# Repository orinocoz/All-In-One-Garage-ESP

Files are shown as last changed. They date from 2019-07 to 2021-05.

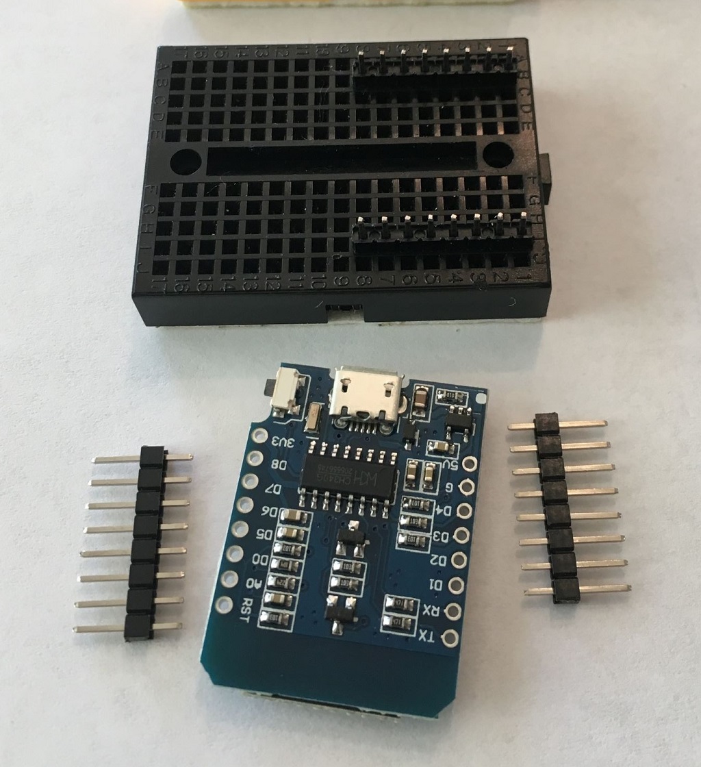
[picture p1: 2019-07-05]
Docs/D1 Mini Some Soldering Required.jpg

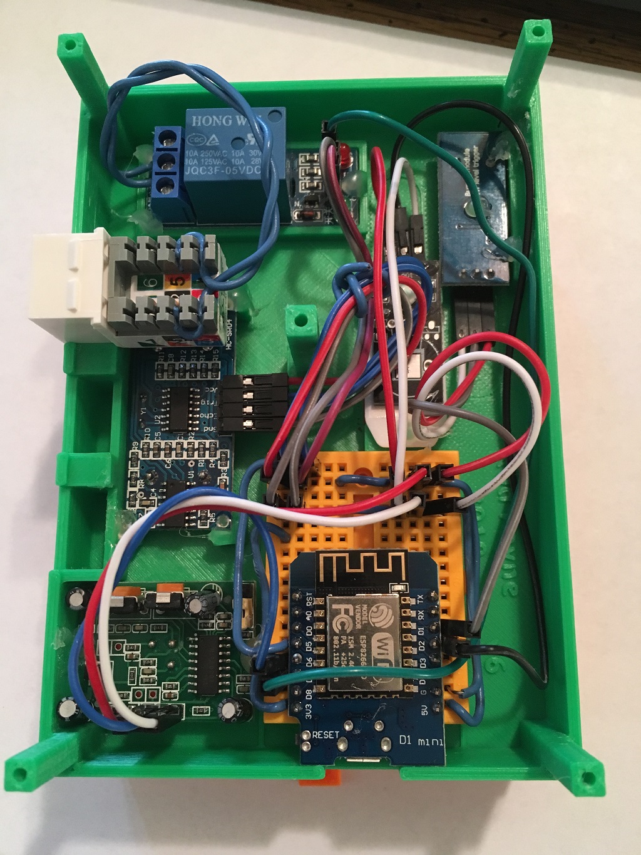
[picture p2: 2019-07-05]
Docs/Controller Wiring.JPG

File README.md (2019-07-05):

# All-In-One-Garage-ESP
All-In-One Garage Controller on ESP8266 (WeMos D1 Mini)

Communicates over WiFi to MQTT broker, for Home Assistant or other system.
As built, for two car bays with one door.

## Parts List

- [WeMos D1 Mini Module](<https://www.aliexpress.com/item/D1-mini-Mini-NodeMcu-4M-bytes-Lua-WIFI-Internet-of-Things-development-board-based-ESP8266-by/32644199530.html>)
- [Power Supply 5V Micro USB](<https://www.amazon.com/Raspberry-Power-Supply-Adapter-Charger/dp/B0719SX3GC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>)
- [5V Relay Module (2 needed, or a 2 channel relay, if for two doors)](<https://www.aliexpress.com/item/one-1-channel-relay-module-with-optocoupler-isolation-fully-compatible-with-3-3V-and-5V-Signal/32869288345.html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>) - Relay needs to trip with 3.3V and **_low current_**.
- [Magnetic Contact Switch (2 needed if for two doors)](<https://www.aliexpress.com/item/NO-NC-Wired-Door-Magnetic-Contact-Switch-alarm-Reed-switches-door-sensor-for-Home-Alarm-System/32832532279.html>)
- Jumper wires, etc.

Following are optional:
- [HC-SR04 Distance Sensor (1/5, 2 needed if for two car bays)](<https://www.amazon.com/gp/product/B01GVDV6DY/ref=oh_aui_detailpage_o01_s02?ie=UTF8&psc=1>)
- [Passive Buzzer Alarm Module](<https://www.dx.com/p/passive-low-level-buzzer-alarm-module-for-arduino-dc-3-5v-5v-2017987#.XAF3AeJlCUk>)
- [RJ11 Keystone Jack (2 needed if for one car bay, 4 if for two car bays, 6 if for two doors/two bays)](<https://www.homedepot.com/p/Commercial-Electric-Voice-Grade-Jack-White-5023-WH/206427969>)
- [DHT22 AM2302 Digital Temperature and Humidity Sensor](<https://www.amazon.com/TOOGOO-Digital-Temperature-Humidity-Raspberry/dp/B0757F4KK3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>)
- [HC-SR501 PIR (motion) sensor](<https://www.adafruit.com/product/189>)
- [Mini Breadboard Kit (1/6)](<https://www.amazon.com/gp/product/B01EV6SBXQ/ref=oh_aui_detailpage_o05_s00?ie=UTF8&psc=1>)
- Main Project Case ([Garage Parts - Main - Bottom.stl](<Garage Parts - Main - Bottom.stl>) and [Garage Parts - Main - Top.stl](<Garage Parts - Main - Top.stl>))
- Remote Project Case if for two car bays ([Garage Parts - Remote - Bottom.stl](<Garage Parts - Remote - Bottom.stl>) and [Garage Parts - Remote - Top.stl](<Garage Parts - Remote - Top.stl>))

Approximate total cost $50.00

## Wiring for one door and two cars

- D1 - Speaker I/O
- D2 - DHT22 Out
- D3 - Don't use, controls run/flash mode
- D4 - Controls LED, but could be used
- G - Left Echo Gnd - Right Echo Gnd (to jack) - DHT22 Gnd(-) - Motion Gnd - Left Relay Gnd - Speaker Gnd - Left Mag Switch N/C
- 5v - Left Echo Vcc - Right Echo Vcc (to jack) - DHT22 Vcc(+) - Motion +5v - Left Relay 5v - Speaker Vcc

- D0 - Right Echo Trig/Echo (to jack)
- D5 - Left Echo Trig/Echo
- D6 - Motion Out
- D7 - Left Relay
- D8 - Left Mag Switch Comm
- 3v - (Maybe Speaker Vcc)

Note: Building for two doors and two bays with all the options will require more ports than the WeMos D1 Mini Module normally supplies.  (The TX/RX ports could be used if you don't need the serial monitor for debugging, but this would require some reprogramming of the sketch.)

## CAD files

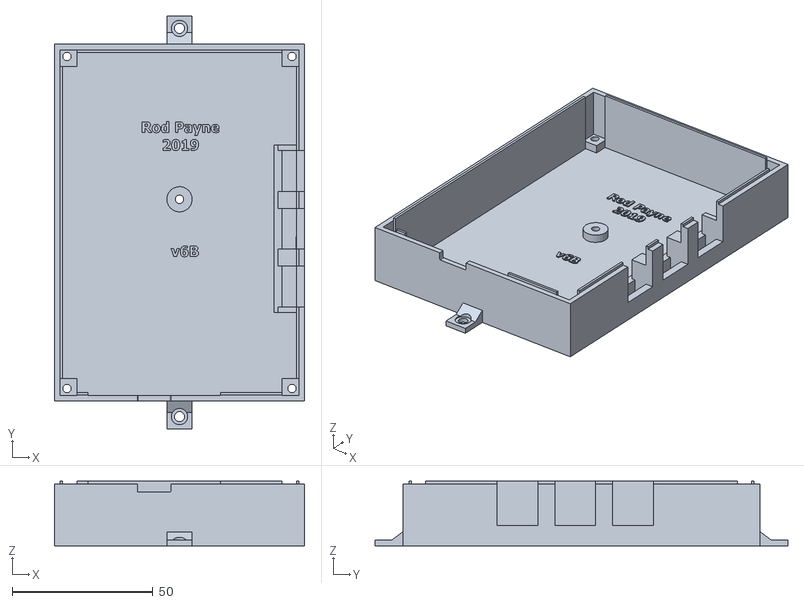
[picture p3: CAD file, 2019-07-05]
Garage Parts - Main - Bottom.stl
89.0 x 146.8 x 23.0

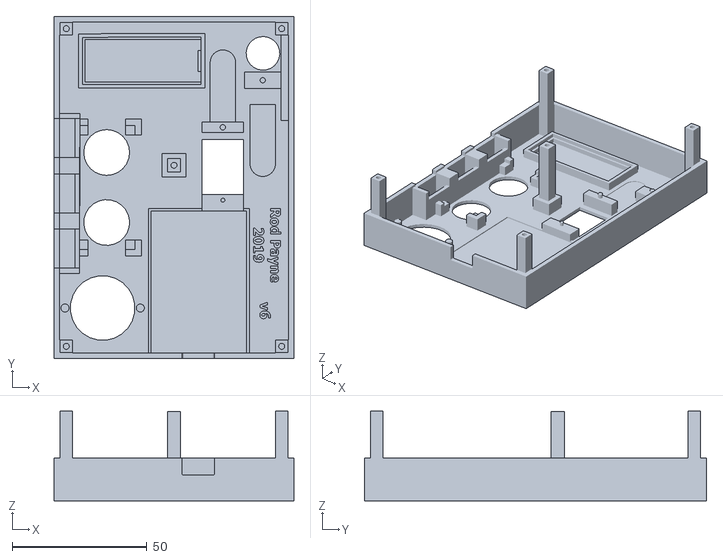
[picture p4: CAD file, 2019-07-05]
Garage Parts - Main - Top.stl
89.0 x 127.0 x 33.4

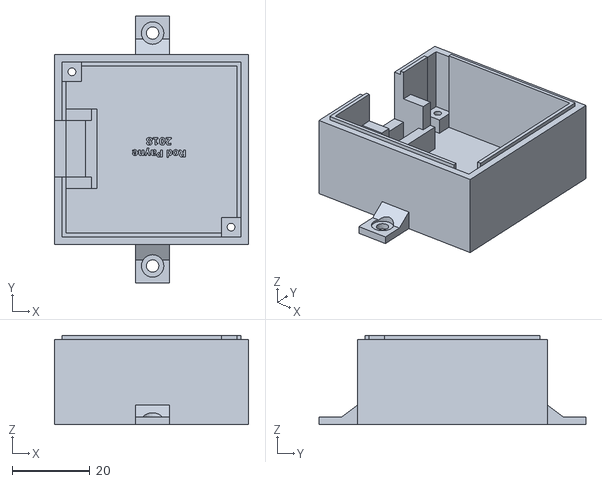
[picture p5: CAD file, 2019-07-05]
Garage Parts - Remote - Bottom.stl
50.0 x 68.8 x 23.0

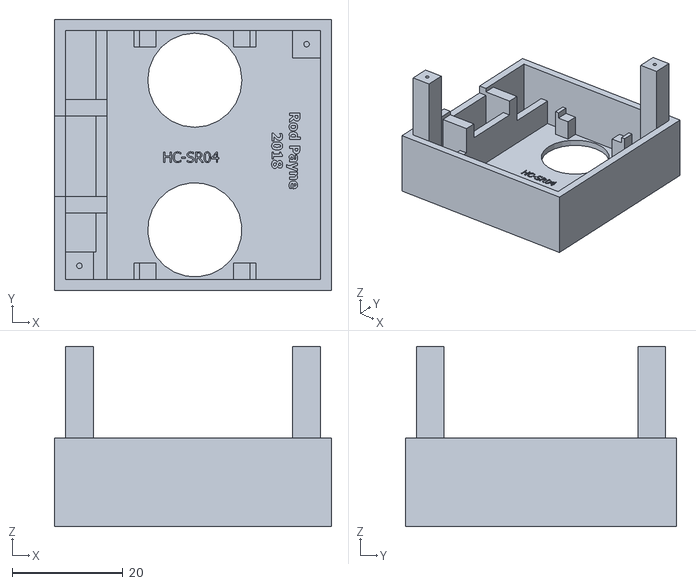
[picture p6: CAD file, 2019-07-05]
Garage Parts - Remote - Top.stl
50.0 x 49.0 x 32.5

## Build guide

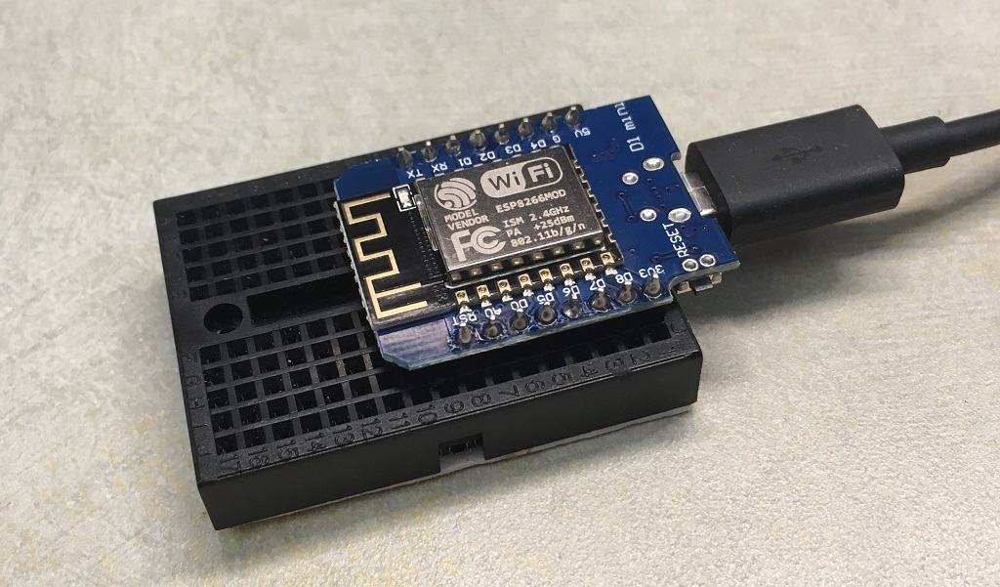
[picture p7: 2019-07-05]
Docs/D1 Mini Soldered Unit.JPG

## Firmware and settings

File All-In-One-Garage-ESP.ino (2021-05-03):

//*------------------------------------------------------------------------------------------------------------------------
//* All-In-One Garage Controller on ESP8266 (WeMos D1 Mini)
//*
//* See https://automatedhome.party/2017/01/06/wifi-garage-door-controller-using-a-wemos-d1-mini/
//* https://github.com/tzapu/WiFiManager/blob/master/examples/AutoConnectWithFSParameters/AutoConnectWithFSParameters.ino
//* Home Assistant MQTT Discovery, see https://home-assistant.io/docs/mqtt/discovery/
//*------------------------------------------------------------------------------------------------------------------------

#include <FS.h>
#include <ESP8266WiFi.h>             //* ESP8266 Core WiFi Library - https://github.com/esp8266/Arduino
#include <DNSServer.h>               //* Local DNS Server to redirect requests to configuration portal
#include <ESP8266WebServer.h>        //* Local WebServer used to serve the configuration portal
#include <WiFiManager.h>             //* WiFi Configuration Magic - //https://github.com/tzapu/WiFiManager
#include <ArduinoJson.h>             //* JSON - https://github.com/bblanchon/ArduinoJson

#define MQTT_MAX_PACKET_SIZE 512
#include <PubSubClient.h>            //* MQTT Client - https://github.com/knolleary/pubsubclient/releases/tag/v2.6

#include <ESP8266mDNS.h>             //* Multicast DNS Responder 
#include <ESP8266HTTPUpdateServer.h> //* Update Over-The-Air (OTA)

#include "pitches.h"
#include "D1MiniPins.h"

//************START CUSTOM PARAMETERS******************//

#include "secrets.h"

#if !defined OTA_USER
#define OTA_USER "admin"
#endif
#if !defined OTA_PASSWORD
#define OTA_PASSWORD "RedactedPassword"
#endif
#if !defined MQTT_USER
#define MQTT_USER "pi"
#endif
#if !defined MQTT_PASSWORD
#define MQTT_PASSWORD "RedactedPassword"
#endif

//*-----------------------------------
//* OTA Firmware Update parameters:
//*-----------------------------------

const char* our_host_name =     "GarageESP";
String unique_client_name =  String(our_host_name) + "-" + String(ESP.getChipId()) + "-" + String(ESP.getFlashChipId());
const char* update_path =       "/WebFirmwareUpgrade";
//* these defaults can be updated on the config page:
char update_username[40] =      OTA_USER;
char update_password[40] =      OTA_PASSWORD;

//*---------------------------------------------------------------------------------
//* Define the magnetic door switch and relay pins for left (or only) garage door:
//*---------------------------------------------------------------------------------

#define LEFT_RELAY_PIN D7
// #define LEFT_DOOR_PIN  Dx

#define LEFT_DOOR_NAME          "Garage Door"
#define LEFT_DOOR_TOPIC         "garage/left/door"
#define DOOR_STATEOPEN              "Open"
#define DOOR_STATECLOSED            "Closed"
#define DOOR_STATEUNKNOWN           "Unknown"
#define DOOR_STATEALERT             "Alert"

String left_door_state = DOOR_STATEUNKNOWN;

//*---------------------------------------------------
//* Define the pins for right garage door (optional):
//*---------------------------------------------------

// #define RIGHT_RELAY_PIN Dx
// #define RIGHT_DOOR_PIN  Dx

#define RIGHT_DOOR_NAME         "Right Garage Door"
#define RIGHT_DOOR_TOPIC        "garage/right/door"

String right_door_state = DOOR_STATEUNKNOWN;

//*-----------------------------------
//* Passive Speaker Buzzer (optional)
//*-----------------------------------

#define SPEAKER_PIN D1
void sound_alert();
void signal_success();
void signal_error();

//*----------------------------------------------------
//* Digital Humidity and Temperature Sensor (optional)
//*----------------------------------------------------

#define DHT_PIN  D2             //* DHT-22 Pin connection
#define DHT_TYPE DHT22          //* DHT Type is DHT22 (AM2302)

#define HUMIDITY_NAME           "Garage Humidity"
#define HUMIDITY_TOPIC          "garage/humidity"
#define TEMPERATURE_NAME        "Garage Temperature"
#define TEMPERATURE_TOPIC       "garage/temperature"

//*----------------------------------------------------
//* Left Car HC-SR04 Distance Sensor (optional)
//*----------------------------------------------------

#define ECHO_TRIGGER_PIN  D5
#define ECHO_DETECT_PIN   D5

#define LEFT_CAR_NAME           "Garage Left Lane"
#define LEFT_CAR_TOPIC          "garage/left/car"

#ifdef ECHO_TRIGGER_PIN
#define CAR_LANE_OCCUPIED           "Detected"
#define CAR_LANE_EMPTY              "Clear"
#define CAR_LANE_UNKNOWN            "Unknown"

#endif

float min_distance_float;
float max_distance_float;
unsigned int max_distance_uint;
//* these defaults can be updated on the config page:
char min_distance[4] = "10";    //* minimum valid distance for detection
char max_distance[4] = "220";   //* maximum valid distance for detection

//*-----------------------------------------------------------------
//* Right Car HC-SR04 Distance Sensor (optional; define Left first)
//*-----------------------------------------------------------------

// #define ECHO_TRIGGER_PIN_RIGHT  Dx
// #define ECHO_DETECT_PIN_RIGHT   Dx

#define RIGHT_CAR_NAME          "Garage Right Lane"
#define RIGHT_CAR_TOPIC         "garage/right/car"

//*-----------------------------------
//* MQTT Parameters
//*-----------------------------------

#define COMMAND_TOPIC           "garage/command"
//* these defaults can be updated on the config page:
char mqtt_server[40] =          "172.19.54.7";
char mqtt_port[6] =             "1883";
char mqtt_user[40] =            MQTT_USER;
char mqtt_pass[40] =            MQTT_PASSWORD;
char mqttDiscoveryPrefix[40] =  "homeassistant";

//*-----------------------------------
//* PIR Motion Detector (optional)
//*-----------------------------------

#define MOTION_PIN D6

#define MOTION_NAME             "Garage Motion"
#define MOTION_TOPIC            "garage/motion"
#define MOTION_DETECTED             "Detected"
#define MOTION_NOT_DETECTED         "Clear"

//************END CUSTOM PARAMS******************//

#ifdef DHT_PIN
//void get_humidity_and_temperature();
#include "DHT.h"                //* DHT Libraries from Adafruit; Dependant upon Adafruit_Sensors Library
DHT dht(DHT_PIN, DHT_TYPE);     //* Initialize DHT sensor for normal 16mhz Arduino 
#endif

#ifdef ECHO_TRIGGER_PIN
//* Include NewPing Library
#include "NewPingESP8266.h"
float soundcm =  0.0343;        //* Stores calculated speed of sound in cm/ms
int iterations = 3;             //* Number of pings to average together
unsigned long last_occupancy_check_millis = 0;
#endif

#ifdef ECHO_TRIGGER_PIN
//    NewPingESP8266 sonar1(ECHO_TRIGGER_PIN, ECHO_DETECT_PIN, max_distance_uint);
NewPingESP8266 sonar1(ECHO_TRIGGER_PIN, ECHO_DETECT_PIN, 500);

#ifdef ECHO_TRIGGER_PIN_RIGHT
//        NewPingESP8266 sonar2(ECHO_TRIGGER_PIN_RIGHT, ECHO_DETECT_PIN_RIGHT, max_distance_uint);
NewPingESP8266 sonar2(ECHO_TRIGGER_PIN_RIGHT, ECHO_DETECT_PIN_RIGHT, 500);
#endif
#endif

//* This can be used to output the date the code was compiled
const char compile_date[] = __DATE__ " " __TIME__;

//* Web Server Globals:
ESP8266WebServer httpServer(80);
ESP8266HTTPUpdateServer httpUpdater;

//* MQTT Globals:
WiFiClient espClient;
PubSubClient mqttClient(espClient);

void mqtt_callback(char* topic, byte* payload, unsigned int length);
void connect_to_mqtt_broker();

//*-----------------------------------
//* WiFiManager Globals:
//*-----------------------------------

//* callback notifying us that config mode is being entered
void configModeCallback (WiFiManager *myWiFiManager) {
  Serial.println("Entering config mode...");
  //    Serial.println(WiFi.softAPIP());
  //    Serial.println(myWiFiManager->getConfigPortalSSID());
}

//* flag for saving data
bool shouldSaveConfig = false;

//* callback notifying us of successful connection and the need to save config
void saveConfigCallback () {
  Serial.println("saveConfigCallback");
  shouldSaveConfig = true;
}

//*------------------------------------------------------------------------
//* The setup function runs once when you press reset or power the board:
//*------------------------------------------------------------------------

void setup() {
  Serial.begin(115200);
  while (!Serial) {
    ; // wait for serial port to connect.
  }
  delay(1000);

  Serial.println(__FILE__);
  Serial.print("Compile date: ");
  Serial.println(compile_date);

  Serial.println(unique_client_name);

  //* Set Relay(output) and Door(input) pins
#ifdef LEFT_RELAY_PIN
pinMode(LEFT_RELAY_PIN, LOW);
pinMode(LEFT_RELAY_PIN, OUTPUT);
pinMode(LEFT_RELAY_PIN, LOW);
#endif
#ifdef RIGHT_RELAY_PIN
pinMode(RIGHT_RELAY_PIN, LOW);
pinMode(RIGHT_RELAY_PIN, OUTPUT);
pinMode(RIGHT_RELAY_PIN, LOW);
#endif
#ifdef LEFT_DOOR_PIN
pinMode(LEFT_DOOR_PIN, INPUT_PULLUP);
#endif
#ifdef RIGHT_DOOR_PIN
pinMode(RIGHT_DOOR_PIN, INPUT_PULLUP);
#endif

#ifdef SPEAKER_PIN
pinMode(SPEAKER_PIN, OUTPUT);
pinMode(SPEAKER_PIN, LOW);
#endif

#ifdef DHT_PIN
dht.begin();
#endif

  //* clean FS, for testing
  // SPIFFS.format();

  //* read configuration from FS json
  Serial.println("Mounting FS...");

  if (SPIFFS.begin()) {
    Serial.println("FS mounted.");
    if (SPIFFS.exists("/config.json")) {
      //* file exists, reading and loading
      Serial.println("Reading config file...");
      File configFile = SPIFFS.open("/config.json", "r");
      if (configFile) {
        Serial.println("Opened config file.");
        size_t size = configFile.size();
        //* Allocate a buffer to store contents of the file.
        std::unique_ptr<char[]> buf(new char[size]);

        configFile.readBytes(buf.get(), size);
        DynamicJsonBuffer jsonBuffer;
        JsonObject& json = jsonBuffer.parseObject(buf.get());
        json.printTo(Serial);
        if (json.success()) {
          Serial.println("\nParsed json.");

          strcpy(mqtt_server, json["mqtt_server"]);
          strcpy(mqtt_port, json["mqtt_port"]);
          strcpy(mqtt_user, json["mqtt_user"]);
          strcpy(mqtt_pass, json["mqtt_pass"]);
          strcpy(mqttDiscoveryPrefix, json["mqttDiscoveryPrefix"]);
          strcpy(update_username, json["update_username"]);
          strcpy(update_password, json["update_password"]);
//#ifdef ECHO_TRIGGER_PIN
strcpy(min_distance, json["min_distance"]);
strcpy(max_distance, json["max_distance"]);
//#endif
} else {
Serial.println("Failed to load json config.");
}
configFile.close();
}
}
} else {
Serial.println("Failed to mount FS.");
}
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
          void loop() {
            current_millis = millis();

            //* If WiFi is not connected, restart the system:
            if (WiFi.status() != WL_CONNECTED) {
              Serial.println("WiFi is not connected, restarting the system....");
              signal_error();
              ESP.restart();
            }
            //* If MQTT client isn't connected to the MQTT broker, reconnect:
            if (!mqttClient.connected()) {
              connect_to_mqtt_broker();
            }

#ifdef DHT_PIN
get_humidity_and_temperature();        //* (improves accuracy of distance sensor)
#endif

#ifdef ECHO_TRIGGER_PIN
if (last_occupancy_check_millis == 0) {
check_occupancy();                 //* check sonar for cars at least once
} else if (left_door_state != DOOR_STATECLOSED && left_door_state != DOOR_STATEUNKNOWN) {          //* (occupancy will probably not change if door is closed)
check_occupancy();                 //* check sonar for cars at least once
} else if (right_door_state != DOOR_STATECLOSED && right_door_state != DOOR_STATEUNKNOWN) {
check_occupancy();                 //* check sonar for cars
}
#endif

#ifdef MOTION_PIN
check_for_motion();                    //* check PIR for motion
#endif

            check_door_state();                    //* check if the door is open or closed

            mqttClient.loop();                         //* the mqtt function that processes MQTT messages

            httpServer.handleClient();             //* handles requests for the firmware update page
          }

          //*----------------------
          //* PIR Motion Detector
          //*----------------------

#ifdef MOTION_PIN
int motion_detected = 0;
unsigned long last_motion_report_millis = 0;
unsigned long first_motion_check_millis = current_millis + 60000; 		//* PIR needs to stabilize for a minute.

    void check_for_motion() {
		if (current_millis > first_motion_check_millis) {  
            int previous_motion_detected = motion_detected;
            motion_detected = digitalRead(MOTION_PIN);
            //    Serial.println(motion_detected);
            if ((last_motion_report_millis == 0) || (motion_detected != previous_motion_detected)  || (current_millis - last_motion_report_millis > 3600000)) { //* report at least once per hour to resync
              last_motion_report_millis = current_millis;
              String motion_report;
              if (motion_detected == 0) {
                motion_report = MOTION_NOT_DETECTED;
              } else {
                motion_report = MOTION_DETECTED;
              }
              mqttClient.publish(MOTION_TOPIC, motion_report.c_str());
              Serial.print("Motion: ");
              Serial.print(motion_detected);
              Serial.print(" ");
              Serial.println(motion_report);

              if (motion_detected != previous_motion_detected) {
                if (motion_report == MOTION_DETECTED) {
                  signal_beep(NOTE_G4);
                }
              }
            }
        }
	}
#endif

          //*------------------------------------------
          //* Digital Humidity and Temperature Sensor
          //*------------------------------------------

          float current_humidity = 50;    //* Stores humidity value in percent
          float current_temperature = 60; //* Stores temperature value in degrees fahrenheit
#ifdef DHT_PIN
unsigned long lastDHT_millis = 0;
unsigned long last_humidity_report_millis = 0;
unsigned long last_temperature_report_millis = 0;

          void get_humidity_and_temperature() {
            char outstr[6];
            outstr[5] = '\0';
            //* Smallest DHT-22 sensor sampling rate = 0.5 Hz (once every two seconds)
            if ((lastDHT_millis == 0) || (current_millis - lastDHT_millis > 60000)) {  //* sample every 60 seconds
              lastDHT_millis = current_millis;

              float previous_humidity = current_humidity;
              current_humidity = dht.readHumidity();  //* Get Humidity value
              if (! isnan(current_humidity)) {
                if ((last_humidity_report_millis == 0) || (current_humidity != previous_humidity) || (current_millis - last_humidity_report_millis > 3600000)) { //* report at least once per hour
                  last_humidity_report_millis = current_millis;
                  // no matching function for call to 'PubSubClient::publish(const char [16], float&)'   -->   client.publish(HUMIDITY_TOPIC, current_humidity);
                  dtostrf(current_humidity, 5, 0, outstr);
                  mqttClient.publish(HUMIDITY_TOPIC, outstr);
                  Serial.print("Humidity: ");
                  Serial.print(current_humidity);
                  Serial.println(" %");
                }
              }
              float previous_temperature = current_temperature;
              current_temperature = dht.readTemperature(true);  //* Get Temperature value (isFahrenheit = true)
              if (! isnan(current_temperature)) {
                if ((last_temperature_report_millis == 0) || ( current_temperature != previous_temperature) || (current_millis - last_temperature_report_millis > 3600000)) { //* report at least once per hour
                  last_temperature_report_millis = current_millis;
                  // no matching function for call to 'PubSubClient::publish(const char [19], float&)'   -->   mqttClient.publish(TEMPERATURE_TOPIC, previous_temperature);
                  dtostrf(current_temperature, 5, 1, outstr);
                  mqttClient.publish(TEMPERATURE_TOPIC, outstr);
                  Serial.print("Temperature: ");
                  Serial.print(current_temperature);
                  Serial.println(" F");
                }
              }
            }
          }
#endif

          //*--------------------------
          //* HC-SR04 Distance Sensor
          //*--------------------------

#ifdef ECHO_TRIGGER_PIN

          float duration1; //* Stores First HC-SR04 pulse duration value
          float distance1; //* Stores calculated distance in cm for First Sensor
          char* left_car_lane = CAR_LANE_UNKNOWN;

#ifdef ECHO_TRIGGER_PIN_RIGHT
float duration2; //* Stores Second HC-SR04 pulse duration value
float distance2; //* Stores calculated distance in cm for Second Sensor
char* right_car_lane = CAR_LANE_UNKNOWN;
#endif

          void check_occupancy() {
            if (last_occupancy_check_millis == 0 || (current_millis - last_occupancy_check_millis) > 300000) { //* check every 5 minutes
              last_occupancy_check_millis = current_millis;

              //* Calculate the Speed of Sound in cm/ms
              soundcm = (331.4 + (0.606 * current_temperature) + (0.0124 * current_humidity)) / 10000;

#ifdef ECHO_TRIGGER_PIN
//* Measure duration for first sensor
duration1 = sonar1.ping_median(iterations);

              //* Calculate the distance
              distance1 = (duration1 / 2) * soundcm;
              if (! isnan(distance1)) {

                Serial.print("Left distance: ");
                Serial.print(distance1);
                Serial.println(" cm");

                char* last_left_car_lane = left_car_lane; //* save previous state
                if ((distance1 > min_distance_float) && (distance1 < max_distance_float)) {
                  left_car_lane = CAR_LANE_OCCUPIED;
                } else {
                  left_car_lane = CAR_LANE_EMPTY;
                }

                if (last_left_car_lane != left_car_lane) {
                  mqttClient.publish(LEFT_CAR_TOPIC, left_car_lane, true);
                  Serial.print("Left car lane: ");
                  Serial.println(left_car_lane);
                }
              }
#endif
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
